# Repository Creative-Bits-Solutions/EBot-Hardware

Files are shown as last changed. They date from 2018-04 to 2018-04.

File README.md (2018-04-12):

# EBot-Hardware
EBot is a DIY ecosystem developed for students, kids, artists, and robotics enthusiasts to learn, explore and build working prototypes through experiments and games. Entire system includes an electronic development board with wide range of compactable sensors, graphical programming software based on Google Blockly, bunch of wheels, gears, motors, shafts and plastics, books and study materials that help to learn all basic concepts of mechanical designing, programing and electronic prototyping

We focus on STEM education to improve imagination, reasoning, analytical thinking and problem solving skills of kids. Let them Play, Make and Learn with EBot system.

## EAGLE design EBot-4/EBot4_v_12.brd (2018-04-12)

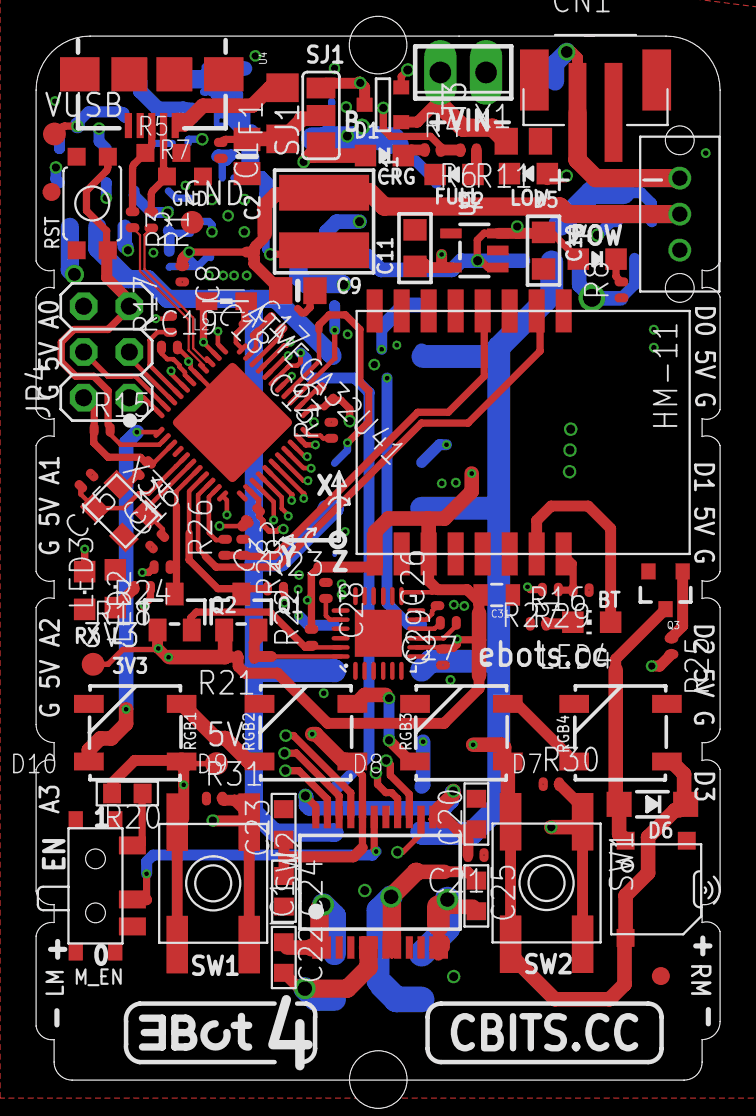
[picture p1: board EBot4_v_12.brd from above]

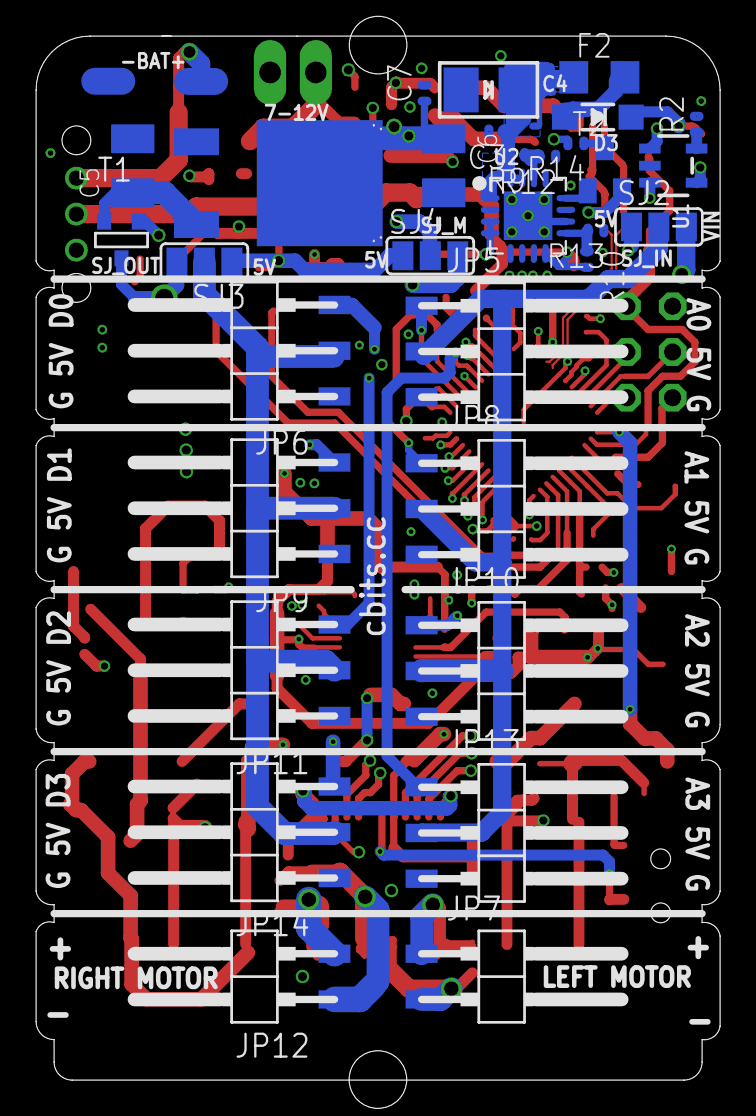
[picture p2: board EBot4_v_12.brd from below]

Board: 4 copper layers, 38.0 x 58.0 mm, 126 parts (33 on the bottom side), 84 nets.

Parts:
3V3, 5V: TPB1,27; B1,27
ATMEGA32U41: ATMEGA32U4-XUMU; QFN44ML7X7
AZ1084C1: AZ1084C
C1, C7, C12, C13, C14, C18: 100n; C0402
C2: 4.7µF; 0805-NO
C3: 2.2uF; C0402
C4: 100uF/6V; EIA3528-21/B-R
C5, C6: 22u; SMC_B
C8, C21, C26, C27: 0.1uF; C0402
C9: 10uF; 0805-NO
C10, C11: 10µF; _0805
C15, C16: 22pF; C0402
C17, C19: 1uF; C0402
C20, C23: 10uf; C0603
C22, C25: 0.1u; C0603
C24: 0.1uf; C0603
C28: 2.2nF; C0402
C29: 10nF; C0402
C31: 0.1uF; 0805
CN1: JST-PH-2-SMT
D1: YELLOW; CHIPLED_0805_NOOUTLINE
D2: GREEN; CHIPLED_0805_NOOUTLINE
D3, D6: MBR120; SOD-123
D4: red; CHIPLED_0805_NOOUTLINE
D5: RED; CHIPLED_0805_NOOUTLINE
D7, D8, D9, D10: WS2812B
EBOT_LOGO2: EBOT_NAME_6MM
F1, F2: 500mA; R1206
GND: TPB1,27; B1,27
HM-111: HM-11
IC1: TB6612FNG; SSOP24
JP2, JP3: FIDUCIAL1X2; FIDUCIAL-1X2
JP4: 3x2M; 2X03
JP5, JP6, JP8, JP9, JP10, JP11, JP13, JP14: 1X03SMD/90
JP7, JP12: 1X02SMD/90
KMR1: KMR7
L1: VLC5045-6.8uH; INDUCTOR_5X5MM_TDK_VLC5045
L2: MH2029-300Y; 0805
LED2: yellow; CHIPLED_0805
LED3: BLUE; CHIPLED_0805
LED4: CHIP-LED0805
MPU-60501: MPU-6050-1; QFN-24-4MM2
ON_OFF_SLIDE1: OS102011MA1QN1
Q1, Q2: BSS138; SOT23-WIDE@1
Q3: 2222A; SOT23-3
R1, R3: 22R; R0402
R2, R28, R29: 2K; R0402
R4: 470; R0402
R5, R7: CG0603MLC-05E; CT/CN0603
R6, R17, R18, R26, R27, R30, R31: 1K; R0402
R8, R14: 1k; R0402
R9, R10: 1.87M; R0402
R11: 10k; R0805
R12: 200K; R0402
R13: 340K; R0402
R15, R19, R21, R22, R23, R24: 10K; R0402
R16: 330; R0402
R20: 10K; R0603
R25: 270; R0402
SJ1, SJ2, SJ3, SJ4: SJ_2
SK-12C04051: SK-12C0405
SPK1: SMT-0540-S-R
SW1, SW2: SPST_TACT-EVQQ2; EVQ-Q2
T1: PMV48XP; SOT-23
T2: MMUN2133LT1G; SC59-BEC
T3: FDN340P/PMV48XP; SOT-23
U1: MCP73831T-2ACI/OT; SOT23-5
U2: TPS61030RSAR; PVQFN-16
U3: RT9193; SOT23-5@1
U4: USB-AB-MICRO-SMD
U$1, U$2: BATCON
VUSB: TPB1,27; B1,27
X1: 2POL254
X3: 16MHz KX-7; CRYSTAL-3.2-2.5

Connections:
+3V3: 3V3.TP, C11.1, C26.2, C29.2, C31.2, HM-111.RESETB, HM-111.VCC, MPU-60501.8, MPU-60501.13, Q1.1, Q2.1, R21.2, R22.2, U3.5
+5V: 5V.TP, ATMEGA32U41.2, ATMEGA32U41.14, ATMEGA32U41.24, ATMEGA32U41.34, AZ1084C1.VOUT, C6.+, C7.1, C10.1, C12.1, C13.1, C14.1, C23.1, C24.1, D4.A, D6.C, D7.1, D8.1, D9.1, D10.1, IC1.20, JP4.2, L2.1, R15.1, R20.2, R23.2, R24.2, SJ2.1, SJ3.1, SJ4.1, SPK1.-, SW1.A, SW1.A', SW2.A, SW2.A', T1.3, T3.2, U3.1, U3.3
A0: ATMEGA32U41.36, JP5.1
A1: ATMEGA32U41.37, JP8.1
A2: ATMEGA32U41.38, JP10.1
A3: ATMEGA32U41.39, JP13.1
A4: ATMEGA32U41.40, JP11.3
A5: ATMEGA32U41.41, JP14.3
AO1': C22.1, IC1.1, IC1.2, JP7.1
AO2': C22.2, IC1.5, IC1.6, JP7.2
AREF: ATMEGA32U41.42, C18.1
AVCC: ATMEGA32U41.44, C17.1, L2.2
BLE_KEY: HM-111.PIO0, R27.1, R29.2
BLE_LED: HM-111.PIO1, LED4.A
BO1': C25.2, IC1.11, IC1.12, JP12.2
BO2': C25.1, IC1.7, IC1.8, JP12.1
D0/RX: ATMEGA32U41.20, HM-111.UART_TX
D1/TX: ATMEGA32U41.21, R26.2
D4/M1: ATMEGA32U41.25, IC1.22
D5*/PWM2: ATMEGA32U41.31, IC1.15
D6*/PWM1: ATMEGA32U41.27, IC1.23
D7: ATMEGA32U41.1, JP9.3
D+: R3.1, R5.1, U4.D+
D-: R1.1, R7.1, U4.D-
GND: ATMEGA32U41.5, ATMEGA32U41.15, ATMEGA32U41.23, ATMEGA32U41.35, ATMEGA32U41.43, ATMEGA32U41.EXP, AZ1084C1.GND, C1.2, C2.2, C3.2, C4.-, C5.-, C6.-, C7.2, C8.2, C9.2, C10.2, C11.2, C12.2, C13.2, C14.2, C15.1, C16.1, C17.2, C18.2, C19.2, C20.2, C21.1, C23.2, C24.2, C26.1, C27.1, C28.1, C29.1, C31.1, CN1.2, D2.C, D5.C, D7.3, D8.3, D9.3, D10.3, GND.TP, HM-111.GND, IC1.3, IC1.4, IC1.9, IC1.10, IC1.18, JP4.6, JP5.3, JP6.1, JP8.3, JP9.1, JP10.3, JP11.1, JP13.3, JP14.1, KMR1.P$1, KMR1.P$2, LED2.C, LED3.C, MPU-60501.1, MPU-60501.9, MPU-60501.11, MPU-60501.18, Q3.2, R2.2, R5.2, R7.2, R8.1, R11.1, R12.1, R13.1, R16.1, R19.2, R28.1, R29.1, R30.1, R31.1, SK-12C04051.R, U1.2, U2.5, U2.6, U2.7, U2.10, U2.13, U2.P$18, U2.P$19, U2.P$20, U2.P$21, U2.P$22, U2.THERMAL, U3.2, U4.GND, U$2.P$1, X1.1, X3.2, X3.4
HWB: ATMEGA32U41.33, R19.1
IO8: ATMEGA32U41.28, JP6.3
IO9*/M3: ATMEGA32U41.29, IC1.17
IO10*: ATMEGA32U41.30, R25.2
IO11*/RGB: ATMEGA32U41.12, D10.4
IO12*/M4: ATMEGA32U41.26, IC1.21
IO13*: ATMEGA32U41.32, R18.1
LBI: R10.1, R13.2, U2.9
LBO: T2.B, U2.12
M2: ATMEGA32U41.22, IC1.16
MISO: ATMEGA32U41.11, JP4.1, R30.2, SW1.B, SW1.B'
MOSI: ATMEGA32U41.10, JP4.4, R31.2, SW2.B, SW2.B'
unnamed: D1.A, SJ1.1, U1.4
unnamed: LED2.A, R17.2
unnamed: C8.1, C9.1, L1.P$1, ON_OFF_SLIDE1.P$2, R10.2, U2.8
unnamed: LED3.A, R18.2
unnamed: D9.4, D10.2
unnamed: D1.C, R4.1
unnamed: D8.4, D9.2
unnamed: HM-111.UART_RX, R26.1, R28.2
unnamed: JP5.2, JP8.2, JP10.2, JP13.2, SJ2.2
unnamed: C28.2, MPU-60501.20
unnamed: C27.2, MPU-60501.10
unnamed: D7.4, D8.2
unnamed: LED4.C, R16.2
unnamed: R4.2, R6.2, U1.1
unnamed: R2.1, U1.5
unnamed: D2.A, R6.1
unnamed: L1.P$2, U2.3, U2.4
unnamed: D4.C, R8.2
unnamed: D5.A, R14.2
unnamed: R14.1, T2.C
unnamed: D3.A, F2.2
unnamed: JP6.2, JP9.2, JP11.2, JP14.2, SJ3.2
unnamed: Q3.1, R25.1
unnamed: F1.2, U4.VBUS
unnamed: C1.1, C2.1, F1.1, SJ1.2
unnamed: R9.1, R12.2, U2.14
unnamed: D6.A, Q3.3, SPK1.+
unnamed: AZ1084C1.VIN, C5.+, T1.2
unnamed: C20.1, C21.2, IC1.13, IC1.14, IC1.24, SJ4.2
unnamed: R20.1, SK-12C04051.L
RD_N: ATMEGA32U41.3, R1.2
RD_P: ATMEGA32U41.4, R3.2
RESET: ATMEGA32U41.13, JP4.5, KMR1.P$3, KMR1.P$4, R15.2
RXLED/SS: ATMEGA32U41.8, R17.1
SCK: ATMEGA32U41.9, JP4.3, R27.2
SCL_3V: MPU-60501.23, Q2.2, R22.1
SCL_5V: ATMEGA32U41.18, Q2.3, R24.1
SDA_3V: MPU-60501.24, Q1.2, R21.1
SDA_5V: ATMEGA32U41.19, Q1.3, R23.1
STBY: IC1.19, SK-12C04051.M
UCAP: ATMEGA32U41.6, C19.1
V+: CN1.1, ON_OFF_SLIDE1.P$3, U1.3, U$1.P$1
VDD: R11.2, SJ2.3, SJ3.3, SJ4.3, T1.1, T3.3, X1.2
VOUT1: C3.1, C4.+, F2.1, R9.2, U2.1, U2.15, U2.16
VUSB: ATMEGA32U41.7, D3.C, SJ1.3, T3.1, VUSB.TP
XTAL1: ATMEGA32U41.17, C16.2, X3.3
XTAL2: ATMEGA32U41.16, C15.2, X3.1

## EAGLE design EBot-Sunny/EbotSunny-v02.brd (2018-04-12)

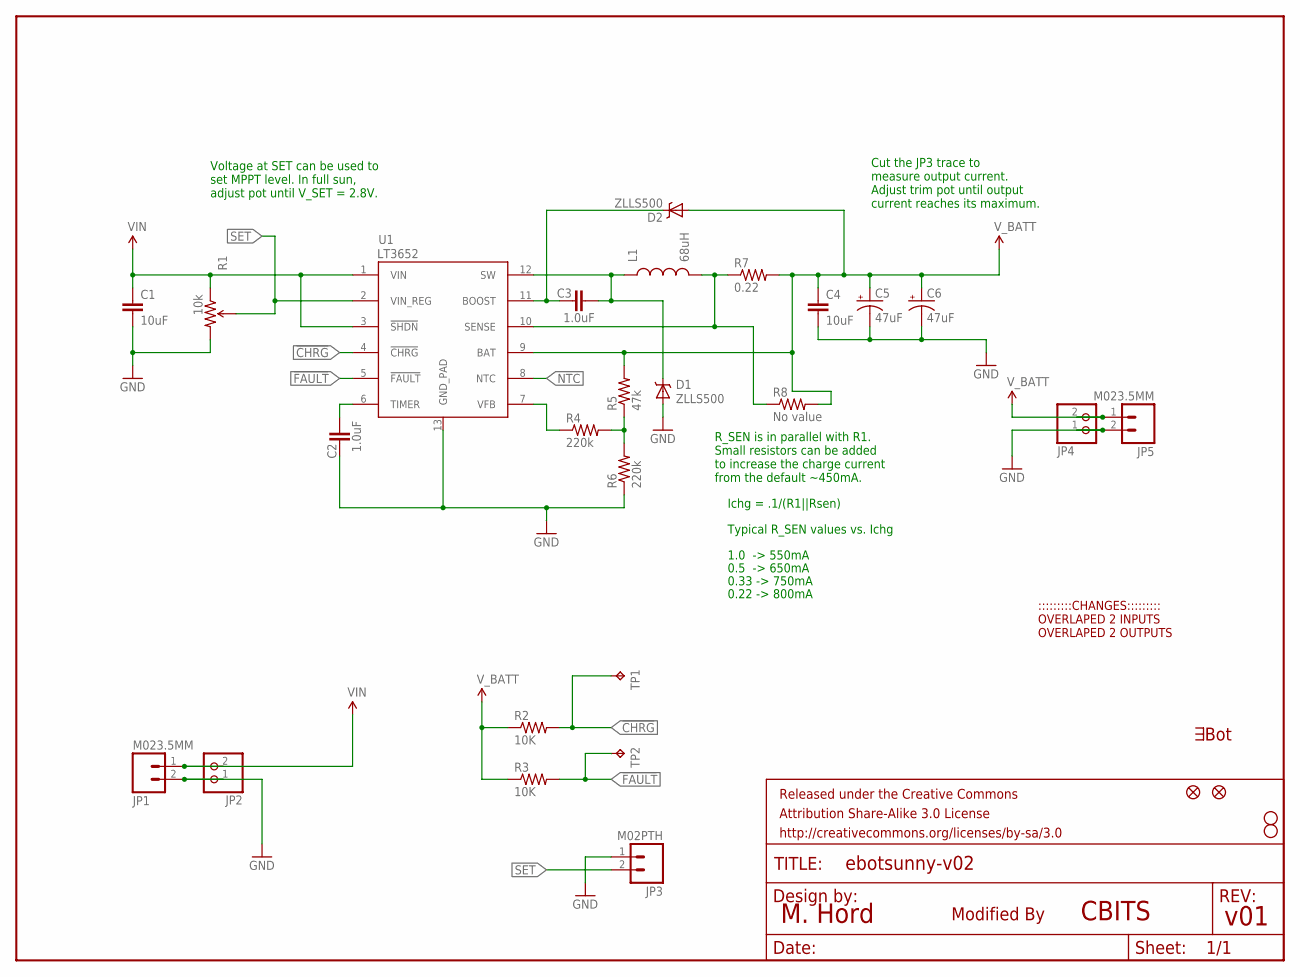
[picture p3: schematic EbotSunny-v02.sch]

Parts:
C1: 10uF; 1210
C2, C3: 1.0uF; 0603-CAP
C4: 10uF; 1206
C5, C6: 47uF; EIA3528
D1, D2: ZLLS500; SOT23
EBOT_LOGO3: EBOT_NAME_6MM
FID1, FID2: FIDUCIAL1X2; FIDUCIAL-1X2
FRAME1: FRAME-LETTER; CREATIVE_COMMONS
JP1, JP5: M023.5MM; SCREWTERMINAL-3.5MM-2
JP2, JP4: PINHD-1X2; 1X02
JP3: M02PTH; 1X02
L1: 68uH; CR75
R1: 10k; TRIMPOT-3MM
R2, R3: 10K; 0603-RES
R4, R6: 220k; 0603-RES
R5: 47k; 0603-RES
R7: 0.22; 0805
R8: No value; 0805
STANDOFF1, STANDOFF2: STAND-OFF
TP1, TP2: TPB1,27; B1,27
U1: LT3652; MSOP-12_GND

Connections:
!CHRG: R2.2, TP1.TP, U1.4 (!CHRG)
!FAULT: R3.2, TP2.TP, U1.5 (!FAULT)
BOOST: C3.1, D2.3 (C), U1.11 (BOOST)
FB: R4.2, R5.1, R6.2
GND: C1.2, C2.1, C4.2, C5.C (-), C6.C (-), D1.1 (A), JP1.2, JP2.1, JP3.1, JP4.1, JP5.2, R1.3 (CW), R6.1, U1.13 (GND_PAD)
unnamed: R4.1, U1.7 (VFB)
NTC: U1.8 (NTC)
SENSE: L1.P$2 (2), R7.1, R8.1, U1.10 (SENSE)
SET: JP3.2, R1.2 (WIPER), U1.2 (VIN_REG)
SW: C3.2, D1.3 (C), L1.P$1 (1), U1.12 (SW)
TIMER: C2.2, U1.6 (TIMER)
VIN: C1.1, JP1.1, JP2.2, R1.1 (CCW), U1.1 (VIN), U1.3 (!SHDN)
V_BATT: C4.1, C5.A (+), C6.A (+), D2.1 (A), JP4.2, JP5.1, R2.1, R3.1, R5.2, R7.2, R8.2, U1.9 (BAT)

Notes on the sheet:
Cut the JP3 trace to measure output current. Adjust trim pot until output current reaches its maximum.
R_SEN is in parallel with R1. Small resistors can be added to increase the charge current from the default ~450mA.
0.22 -> 800mA
Ichg = .1/(R1||Rsen)
Typical R_SEN values vs. Ichg
1.0 -> 550mA
0.33 -> 750mA
0.5 -> 650mA
Voltage at SET can be used to set MPPT level. In full sun, adjust pot until V_SET = 2.8V.
v01
M. Hord
CBITS
Modified By
:::::::::CHANGES::::::::: OVERLAPED 2 INPUTS OVERLAPED 2 OUTPUTS

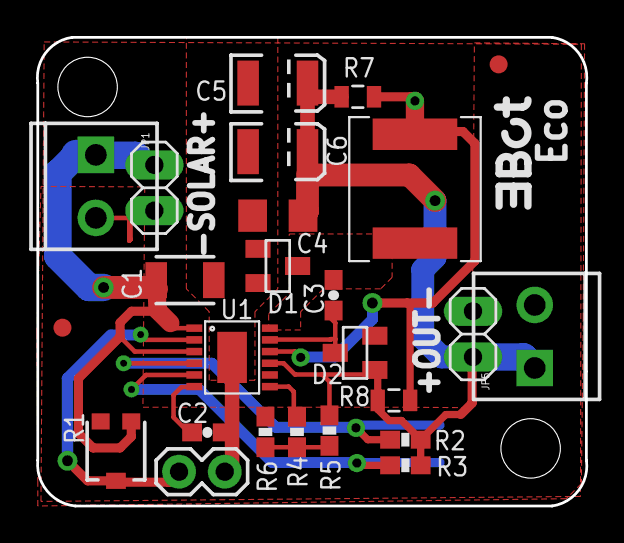
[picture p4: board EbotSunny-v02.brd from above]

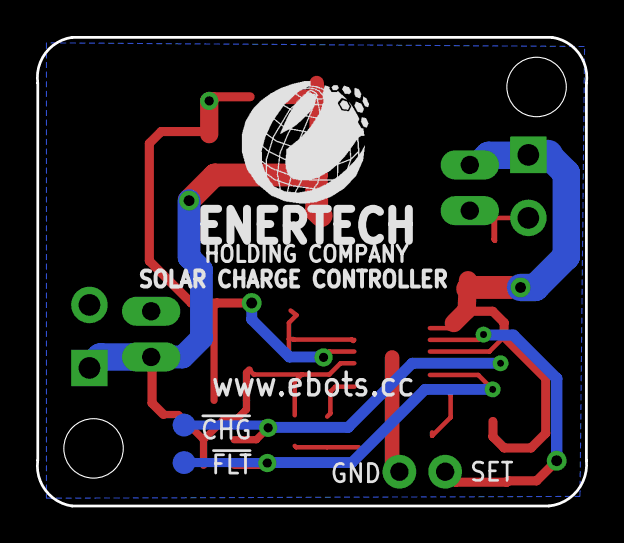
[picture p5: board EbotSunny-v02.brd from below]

Board: 2 copper layers, 30.5 x 26.0 mm, 31 parts (2 on the bottom side), 12 nets.

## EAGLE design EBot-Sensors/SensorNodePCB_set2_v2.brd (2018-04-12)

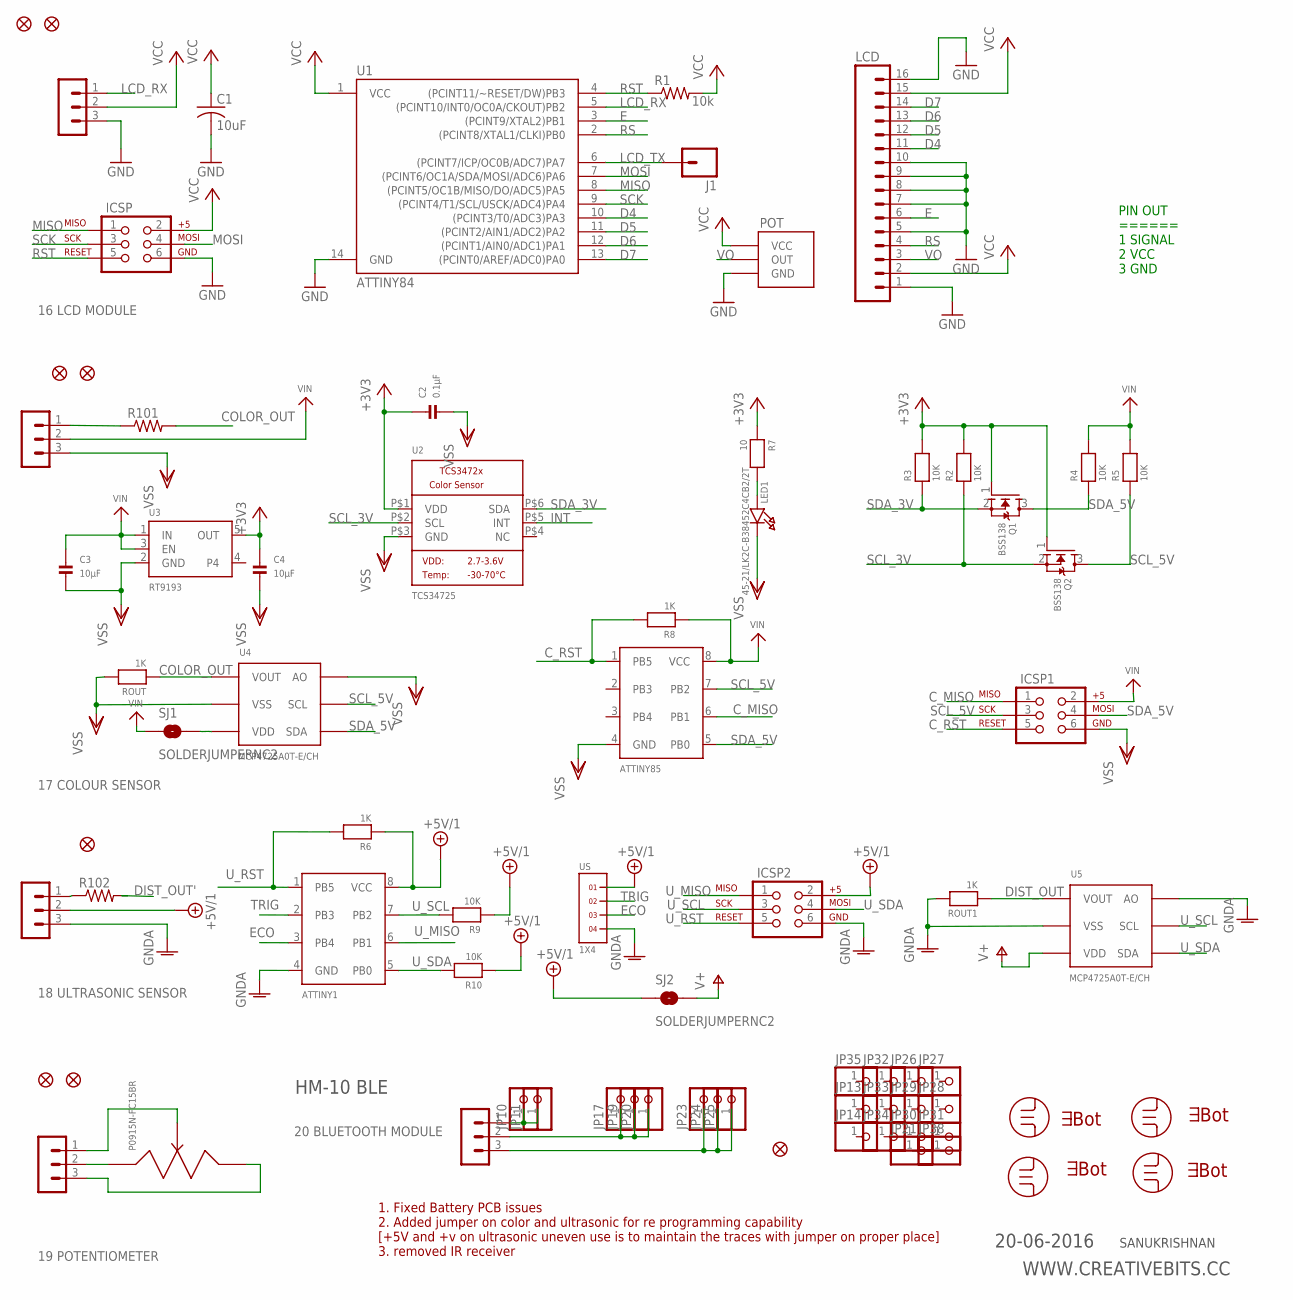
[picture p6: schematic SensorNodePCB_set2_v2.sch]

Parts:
ATTINY1, ATTINY85: ATTINY45; SOIC8
C1: 10uF; C1206
C2: 0.1µF; _0805
C3, C4: 10µF; _0805
COLORSENSOR: MA03-1
ICSP, ICSP1, ICSP2: AVR_SPI_PRG_6NS; 2X3-NS
J1: M01NOSILK-KIT; 1X01NS-KIT
JP1, JP2, JP4, JP6, JP9, JP12, JP15, JP18: FIDUCIAL1X2; FIDUCIAL-1X2
JP10, JP11, JP13, JP14, JP17, JP19, JP20, JP21, JP23, JP24, JP25, JP26, JP27, JP28, JP29, JP30, JP31, JP32, JP33, JP34, JP35, JP38: PINHD-1X1CB; 1X01-CLEANBIG
LCD: M16LONGPADS; 1X16_LONGPADS
LCD_NODE: MA03-1
LED1: 45-21/LK2C-B38452C4CB2/2T; EVERLIGHT_45-21
POT: TRIMMER_EVN
POT1: P0915N-FC15BR
POTENTIOMETER: MA03-1
Q1, Q2: BSS138; SOT23-WIDE
R1: 10k; M0805
R2, R3, R4, R5, R9, R10: 10K; _0805
R6, R8: 1K; _0805
R7: 10; _0805
R101, R102: R-US_M0805; M0805
ROUT, ROUT1: 1K; _0805
SJ1, SJ2: SOLDERJUMPERNC2; SJ_2S-NOTRACE
U1: ATTINY84; SO14
U2: TCS34725; TCS3472_FN6
U3: RT9193; SOT23-5
U4, U5: MCP4725
U$30, U$32, U$33, U$34: EBOT_LOGO_6MMX6MM; EBOT_6MMX6MM
U$35, U$37, U$38, U$39: EBOT_NAME_6MM
ULTRASONICSENSOR, ULTRASONICSENSOR1: MA03-1
US: 1X4

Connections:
+3V3: C2.1, C4.1, Q1.1 (G), Q2.1 (G), R2.2, R3.2, R7.1, U2.P$1 (VDD), U3.5 (OUT)
+5V/1: ATTINY1.8 (VCC), ICSP2.2, R6.1, R9.1, R10.1, SJ2.1, ULTRASONICSENSOR.2, US.1
COLOR_OUT: R101.2, ROUT.1, U4.P$1 (VOUT)
C_MISO: ATTINY85.6 (PB1), ICSP1.1
C_RST: ATTINY85.1 (PB5), ICSP1.5, R8.2
D4: LCD.11, U1.10 ((PCINT3/T0/ADC3)PA3)
D5: LCD.12, U1.11 ((PCINT2/AIN1/ADC2)PA2)
D6: LCD.13, U1.12 ((PCINT1/AIN0/ADC1)PA1)
D7: LCD.14, U1.13 ((PCINT0/AREF/ADC0)PA0)
DIST_OUT: R102.2, ROUT1.1, U5.P$1 (VOUT)
DIST_OUT': R102.1, ULTRASONICSENSOR.1
E: LCD.6, U1.3 ((PCINT9/XTAL2)PB1)
ECO: ATTINY1.3 (PB4), US.3
GND: C1.2, ICSP.6, LCD.1, LCD.5, LCD.7, LCD.8, LCD.9, LCD.10, LCD.16, LCD_NODE.3, POT.P$2 (GND), U1.14 (GND)
GNDA: ATTINY1.4 (GND), ICSP2.6, ROUT1.2, U5.P$2 (VSS), U5.P$6 (AO), ULTRASONICSENSOR.3, US.4
INT: U2.P$5 (INT)
LCD_RX: LCD_NODE.1, U1.5 ((PCINT10/INT0/OC0A/CKOUT)PB2)
LCD_TX: J1.1, U1.6 ((PCINT7/ICP/OC0B/ADC7)PA7)
MISO: ICSP.1, U1.8 ((PCINT5/OC1B/MISO/DO/ADC5)PA5)
MOSI: ICSP.4, U1.7 ((PCINT6/OC1A/SDA/MOSI/ADC6)PA6)
unnamed: LED1.A, R7.2
unnamed: POT1.VCC, POTENTIOMETER.2
unnamed: SJ1.2, U4.P$3 (VDD)
unnamed: COLORSENSOR.1, R101.1
unnamed: POT1.GND, POTENTIOMETER.3
unnamed: JP10.1, JP11.1, ULTRASONICSENSOR1.1
unnamed: JP17.1, JP19.1, JP20.1, ULTRASONICSENSOR1.2
unnamed: JP23.1, JP24.1, JP25.1, ULTRASONICSENSOR1.3
POT_OUT: POT1.OUT, POTENTIOMETER.1
RS: LCD.4, U1.2 ((PCINT8/XTAL1/CLKI)PB0)
RST: ICSP.5, R1.1, U1.4 ((PCINT11/~RESET/DW)PB3)
SCK: ICSP.3, U1.9 ((PCINT4/T1/SCL/USCK/ADC4)PA4)
SCL_3V: Q2.2 (S), R2.1, U2.P$2 (SCL)
SCL_5V: ATTINY85.7 (PB2), ICSP1.3, Q2.3 (D), R5.1, U4.P$5 (SCL)
SDA_3V: Q1.2 (S), R3.1, U2.P$6 (SDA)
SDA_5V: ATTINY85.5 (PB0), ICSP1.4, Q1.3 (D), R4.1, U4.P$4 (SDA)
TRIG: ATTINY1.2 (PB3), US.2
U_MISO: ATTINY1.6 (PB1), ICSP2.1
U_RST: ATTINY1.1 (PB5), ICSP2.5, R6.2
U_SCL: ATTINY1.7 (PB2), ICSP2.3, R9.2, U5.P$5 (SCL)
U_SDA: ATTINY1.5 (PB0), ICSP2.4, R10.2, U5.P$4 (SDA)
V+: SJ2.2, U5.P$3 (VDD)
VCC: C1.1, ICSP.2, LCD.2, LCD.15, LCD_NODE.2, POT.P$1 (VCC), R1.2, U1.1 (VCC)
VIN: ATTINY85.8 (VCC), C3.1, COLORSENSOR.2, ICSP1.2, R4.2, R5.2, R8.1, SJ1.1, U3.1 (IN), U3.3 (EN)
VO: LCD.3, POT.P$3 (OUT)
VSS: ATTINY85.4 (GND), C2.2, C3.2, C4.2, COLORSENSOR.3, ICSP1.6, LED1.K (C), ROUT.2, U2.P$3 (GND), U3.2 (GND), U4.P$2 (VSS), U4.P$6 (AO)

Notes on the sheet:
16 LCD MODULE
PIN OUT ====== 1 SIGNAL 2 VCC 3 GND
17 COLOUR SENSOR
18 ULTRASONIC SENSOR
19 POTENTIOMETER
20 BLUETOOTH MODULE
HM-10 BLE
20-06-2016
WWW.CREATIVEBITS.CC
SANUKRISHNAN
1. Fixed Battery PCB issues 2. Added jumper on color and ultrasonic for re programming capability [+5V and +v on ultrasonic uneven use is to maintain the traces with jumper on proper place] 3. removed IR receiver

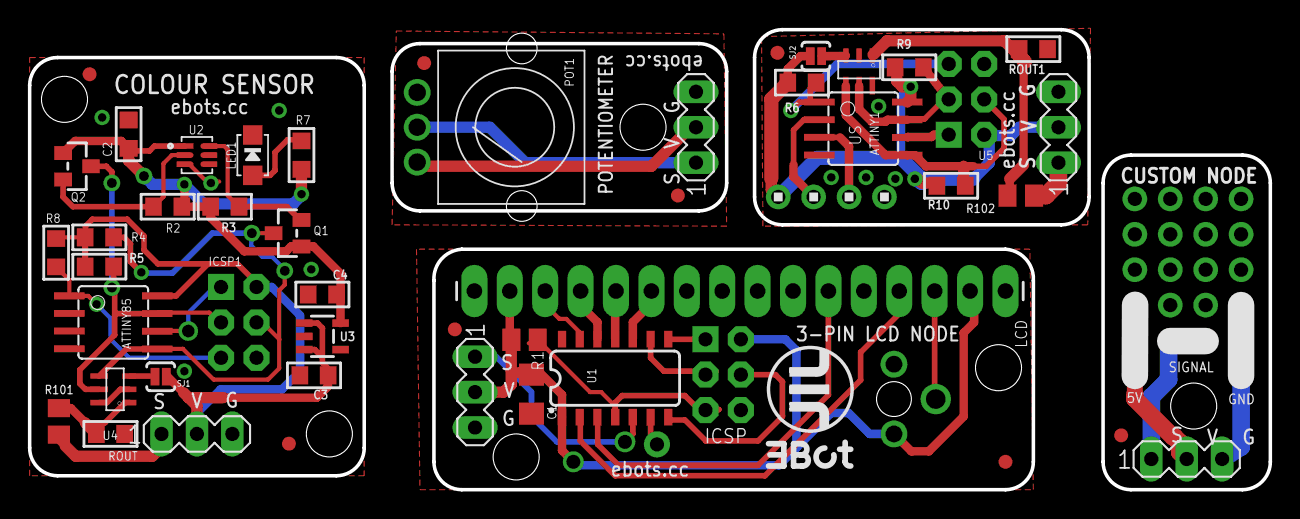
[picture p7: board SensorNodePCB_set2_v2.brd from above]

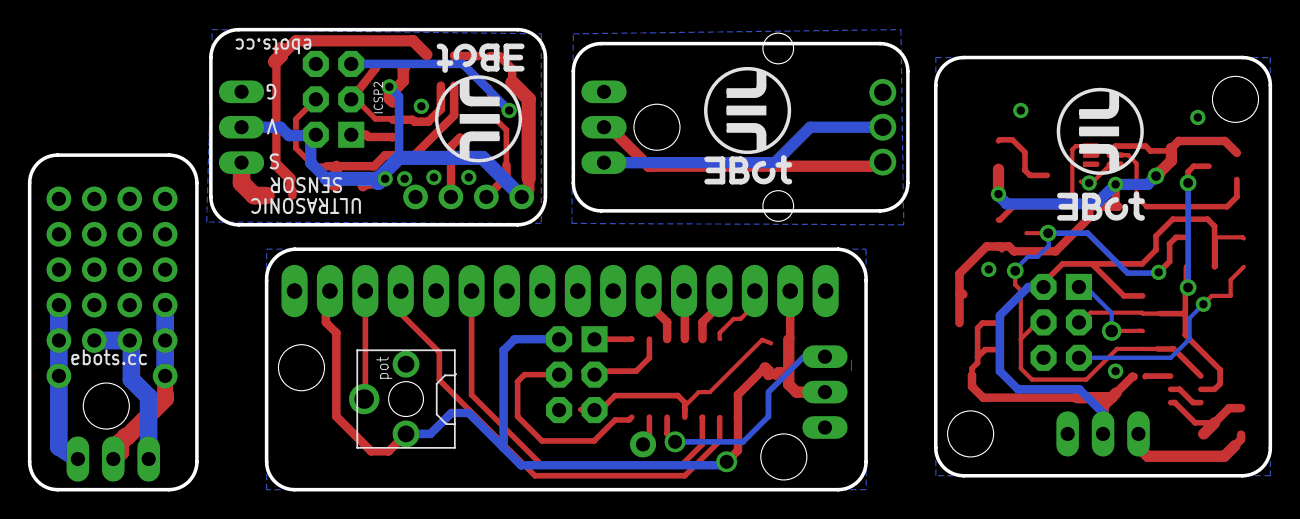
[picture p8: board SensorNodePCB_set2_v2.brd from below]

Board: 2 copper layers, 89.0 x 33.0 mm, 87 parts (8 on the bottom side), 45 nets.

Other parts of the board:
JP3, JP5, JP7, JP8, JP16, JP22: STAND-OFF

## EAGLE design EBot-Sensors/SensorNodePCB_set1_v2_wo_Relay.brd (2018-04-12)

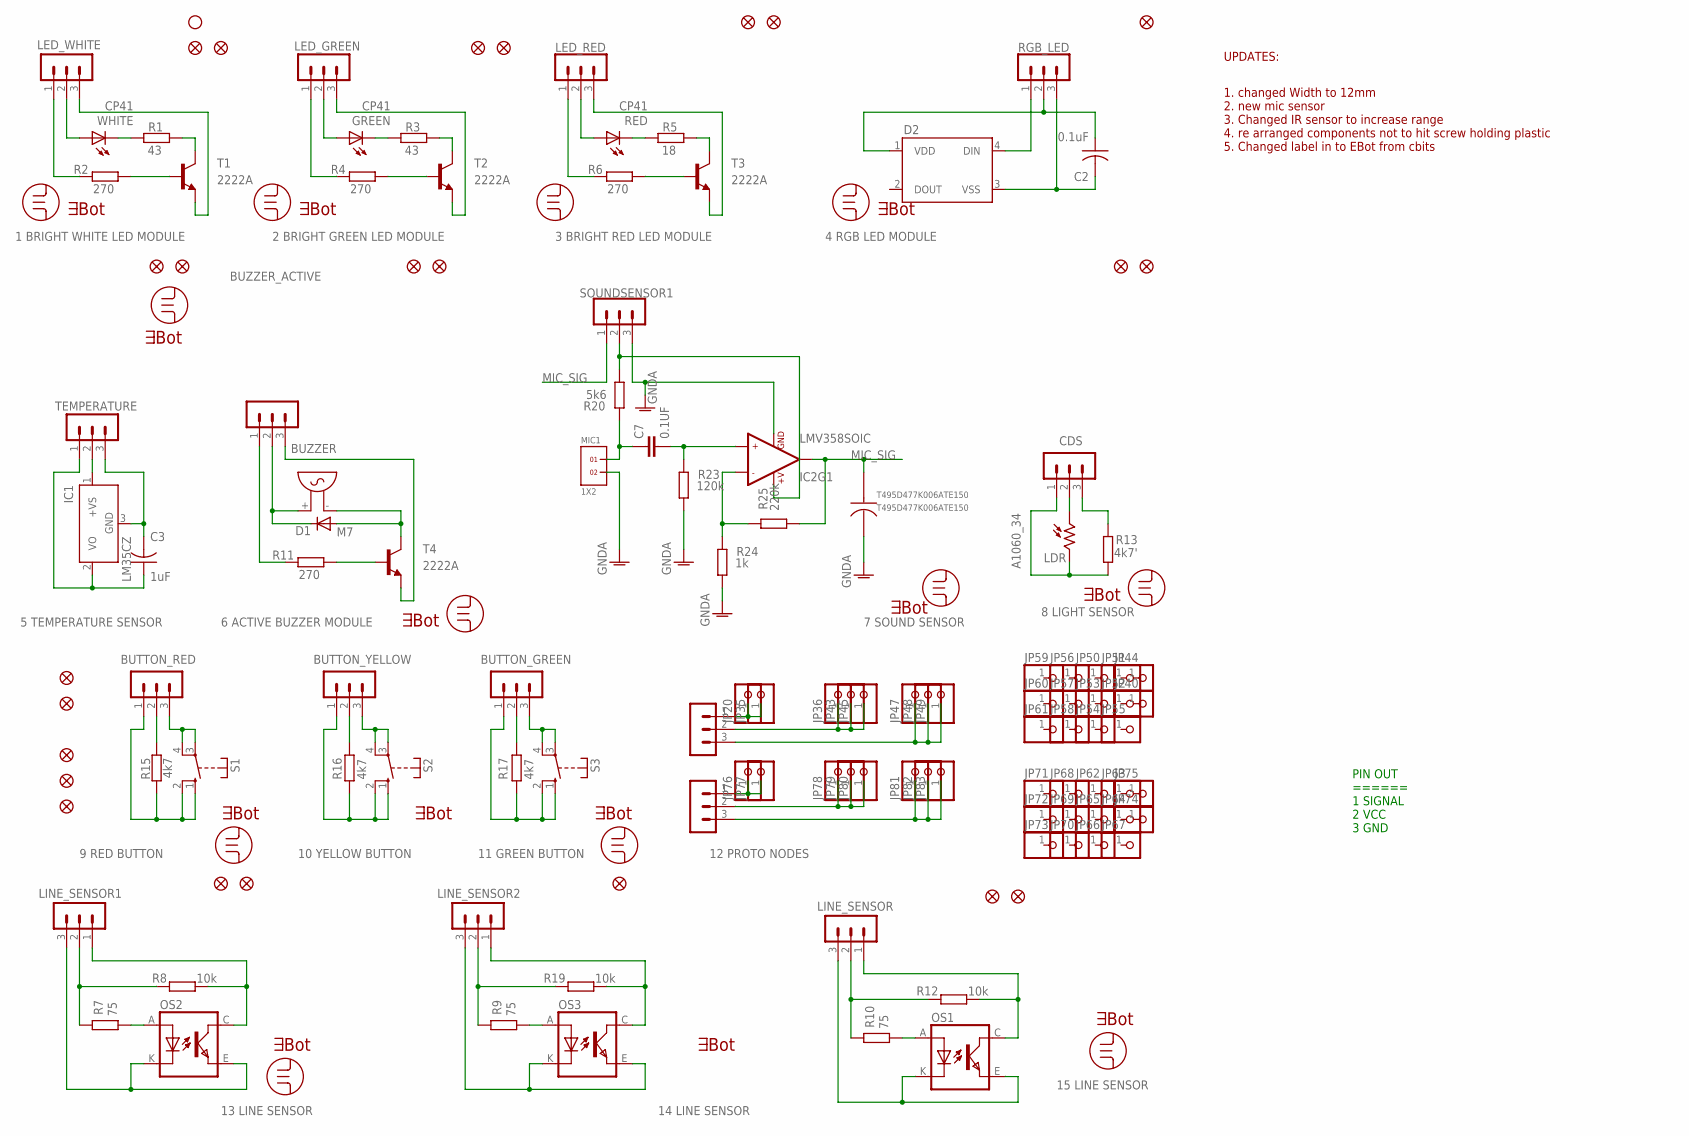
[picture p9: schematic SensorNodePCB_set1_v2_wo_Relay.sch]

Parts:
BUTTON_GREEN: MA03-1
BUTTON_RED: MA03-1
BUTTON_YELLOW: MA03-1
BUZZER: F/QMX
BUZZER_ACTIVE: MA03-1
C2: 0.1uF; C0805
C3: 1uF; C0805
C7: 0.1UF; 0805
CDS: MA03-1
D1: M7; DO214AC
D2: WS2812B
GREEN: CP41; CP41B
IC1: LM35CZ; TO92
IC2: LMV358SOIC; SO08
JP1: STAND-OFF
JP2, JP4, JP6, JP7, JP12, JP18, JP19, JP23, JP24, JP25, JP26, JP28, JP29, JP31, JP32, JP33, JP34, JP37, JP38, JP39, JP41, JP42, JP46: FIDUCIAL1X2; FIDUCIAL-1X2
JP20, JP35, JP36, JP40, JP43, JP44, JP45, JP47, JP48, JP49, JP50, JP51, JP52, JP53, JP54, JP55, JP56, JP57, JP58, JP59, JP60, JP61, JP62, JP63, JP64, JP65, JP66, JP67, JP68, JP69, JP70, JP71, JP72, JP73, JP74, JP75, JP76, JP77, JP78, JP79, JP80, JP81, JP82, JP83: PINHD-1X1CB; 1X01-CLEANBIG
LDR: A1060_34; T0-46-A10XX
LED_GREEN: MA03-1
LED_RED: MA03-1
LED_WHITE: MA03-1
LINE_SENSOR, LINE_SENSOR1, LINE_SENSOR2: MA03-1
MIC1: 1X2
OS1, OS2, OS3: TCRT5000
R1, R3: 43; R0805
R2, R4, R6, R11: 270; R0805
R5: 18; R0805
R7, R9, R10: 75; R0805
R8, R12, R19: 10k; R0805
R13: 4k7'; R0805
R15, R16, R17: 4k7; R0805
R20: 5k6; R0805
R23: 120k; R0805
R24: 1k; R0805
R25: 220k; R0805
RED: CP41; CP41B
RGB_LED: MA03-1
S1, S2, S3: RACON12
SOUNDSENSOR1: MA03-1
T1, T2, T3, T4: 2222A; SOT23-3
TEMPERATURE: MA03-1
U$1, U$3, U$4, U$6, U$8, U$9, U$10, U$12, U$13, U$14, U$15, U$16: EBOT_LOGO_6MMX6MM; EBOT_6MMX6MM
U$11: T495D477K006ATE150
U$17, U$18, U$20, U$21, U$22, U$23, U$24, U$25, U$26, U$27, U$29, U$30, U$31: EBOT_NAME_6MM
ULTRASONICSENSOR1, ULTRASONICSENSOR2: MA03-1
WHITE: CP41; CP41B

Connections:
GNDA: IC2.4 (GND), MIC1.2, R23.1, R24.1, SOUNDSENSOR1.3, U$11.-
MIC_SIG: IC2.1 (OUT1), R25.1, SOUNDSENSOR1.1, U$11.+
unnamed: LED_WHITE.1, R2.2
unnamed: R2.1, T1.1 (B)
unnamed: R1.2, WHITE.1 (C), WHITE.4 (C)
unnamed: R1.1, T1.3 (C)
unnamed: R4.1, T2.1 (B)
unnamed: LED_WHITE.2, WHITE.2 (A), WHITE.3 (A)
unnamed: GREEN.1 (C), GREEN.4 (C), R3.2
unnamed: LED_GREEN.1, R4.2
unnamed: R3.1, T2.3 (C)
unnamed: GREEN.2 (A), GREEN.3 (A), LED_GREEN.2
unnamed: R6.1, T3.1 (B)
unnamed: R5.2, RED.1 (C), RED.4 (C)
unnamed: LED_RED.1, R6.2
unnamed: R5.1, T3.3 (C)
unnamed: LED_RED.2, RED.2 (A), RED.3 (A)
unnamed: D2.4 (DIN), RGB_LED.1
unnamed: C2.1, D2.1 (VDD), RGB_LED.2
unnamed: C2.2, D2.3 (VSS), RGB_LED.3
unnamed: BUTTON_RED.1, R15.2, S1.1 (S), S1.2 (S)
unnamed: BUTTON_RED.2, R15.1
unnamed: BUTTON_YELLOW.1, R16.2, S2.1 (S), S2.2 (S)
unnamed: LED_WHITE.3, T1.2 (E)
unnamed: JP20.1, JP35.1, ULTRASONICSENSOR1.1
unnamed: R11.1, T4.1 (B)
unnamed: LED_GREEN.3, T2.2 (E)
unnamed: LED_RED.3, T3.2 (E)
unnamed: IC1.1 (+VS), TEMPERATURE.2
unnamed: BUZZER_ACTIVE.1, R11.2
unnamed: BUZZER.- (1), D1.A, T4.3 (C)
unnamed: BUZZER.+ (2), BUZZER_ACTIVE.2, D1.C
unnamed: BUZZER_ACTIVE.3, T4.2 (E)
unnamed: C3.2, IC1.3 (GND), TEMPERATURE.3
unnamed: C3.1, IC1.2 (VO), TEMPERATURE.1
unnamed: LINE_SENSOR.3, OS1.E (EMITTER), OS1.K (CATHODE)
unnamed: LINE_SENSOR.2, R10.1, R12.1
unnamed: OS1.A (ANODE), R10.2
unnamed: CDS.1, LDR.2, R13.2
unnamed: CDS.2, LDR.1
unnamed: CDS.3, R13.1
unnamed: LINE_SENSOR.1, OS1.C (COLLECTOR), R12.2
unnamed: JP36.1, JP43.1, JP45.1, ULTRASONICSENSOR1.2
unnamed: JP47.1, JP48.1, JP49.1, ULTRASONICSENSOR1.3
unnamed: JP76.1, JP77.1, ULTRASONICSENSOR2.1
unnamed: BUTTON_GREEN.1, R17.2, S3.1 (S), S3.2 (S)
unnamed: BUTTON_GREEN.3, S3.3, S3.4
unnamed: JP78.1, JP79.1, JP80.1, ULTRASONICSENSOR2.2
unnamed: BUTTON_YELLOW.2, R16.1
unnamed: JP81.1, JP82.1, JP83.1, ULTRASONICSENSOR2.3
unnamed: BUTTON_GREEN.2, R17.1
unnamed: LINE_SENSOR1.3, OS2.E (EMITTER), OS2.K (CATHODE)
unnamed: LINE_SENSOR1.2, R7.1, R8.1
unnamed: LINE_SENSOR1.1, OS2.C (COLLECTOR), R8.2
unnamed: OS2.A (ANODE), R7.2
unnamed: LINE_SENSOR2.3, OS3.E (EMITTER), OS3.K (CATHODE)
unnamed: LINE_SENSOR2.2, R9.1, R19.1
unnamed: LINE_SENSOR2.1, OS3.C (COLLECTOR), R19.2
unnamed: OS3.A (ANODE), R9.2
unnamed: BUTTON_YELLOW.3, S2.3, S2.4
unnamed: IC2.8 (+V), R20.1, SOUNDSENSOR1.2
unnamed: C7.1, MIC1.1, R20.2
unnamed: BUTTON_RED.3, S1.3, S1.4
unnamed: C7.2, IC2.3 (+IN1), R23.2
unnamed: IC2.2 (-IN1), R24.2, R25.2

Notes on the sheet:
1 BRIGHT WHITE LED MODULE
2 BRIGHT GREEN LED MODULE
3 BRIGHT RED LED MODULE
4 RGB LED MODULE
6 ACTIVE BUZZER MODULE
5 TEMPERATURE SENSOR
8 LIGHT SENSOR
7 SOUND SENSOR
PIN OUT ====== 1 SIGNAL 2 VCC 3 GND
9 RED BUTTON
10 YELLOW BUTTON
11 GREEN BUTTON
12 PROTO NODES
13 LINE SENSOR
14 LINE SENSOR
15 LINE SENSOR
UPDATES:
1. changed Width to 12mm 2. new mic sensor 3. Changed IR sensor to increase range 4. re arranged components not to hit screw holding plastic 5. Changed label in to EBot from cbits

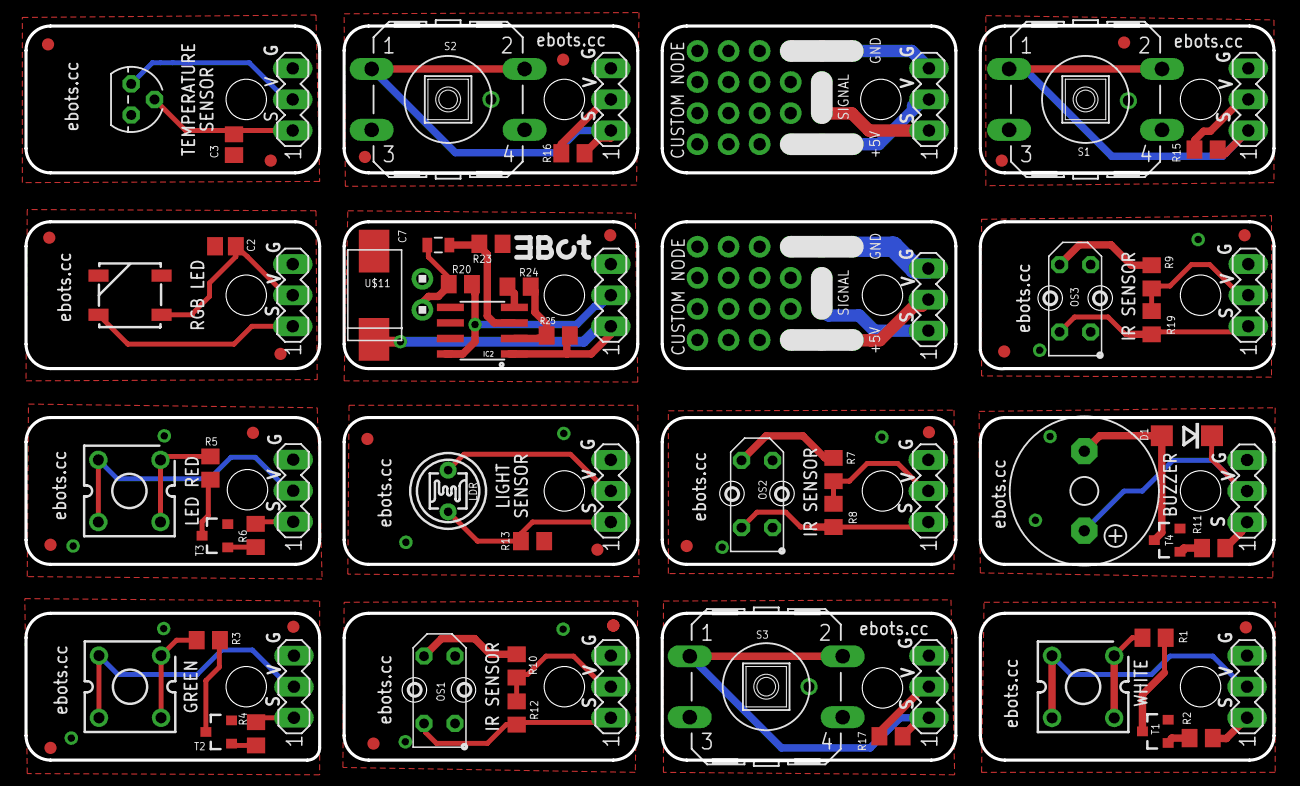
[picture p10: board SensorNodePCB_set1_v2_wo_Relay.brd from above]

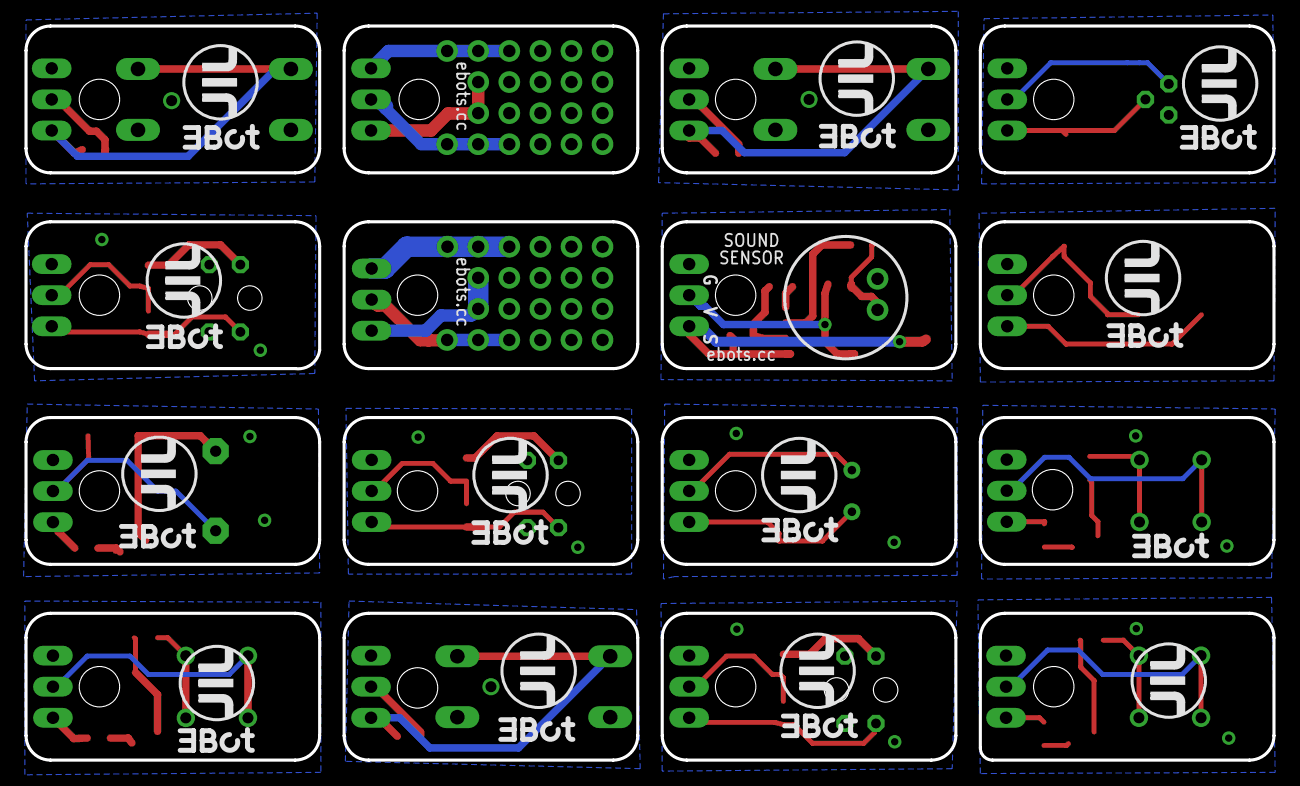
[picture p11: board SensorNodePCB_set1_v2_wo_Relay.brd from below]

Board: 2 copper layers, 102.0 x 60.0 mm, 169 parts (24 on the bottom side), 65 nets.

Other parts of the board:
JP3, JP5, JP8, JP9, JP10, JP11, JP13, JP14, JP15, JP16, JP17, JP21, JP22, JP27, JP30: STAND-OFF

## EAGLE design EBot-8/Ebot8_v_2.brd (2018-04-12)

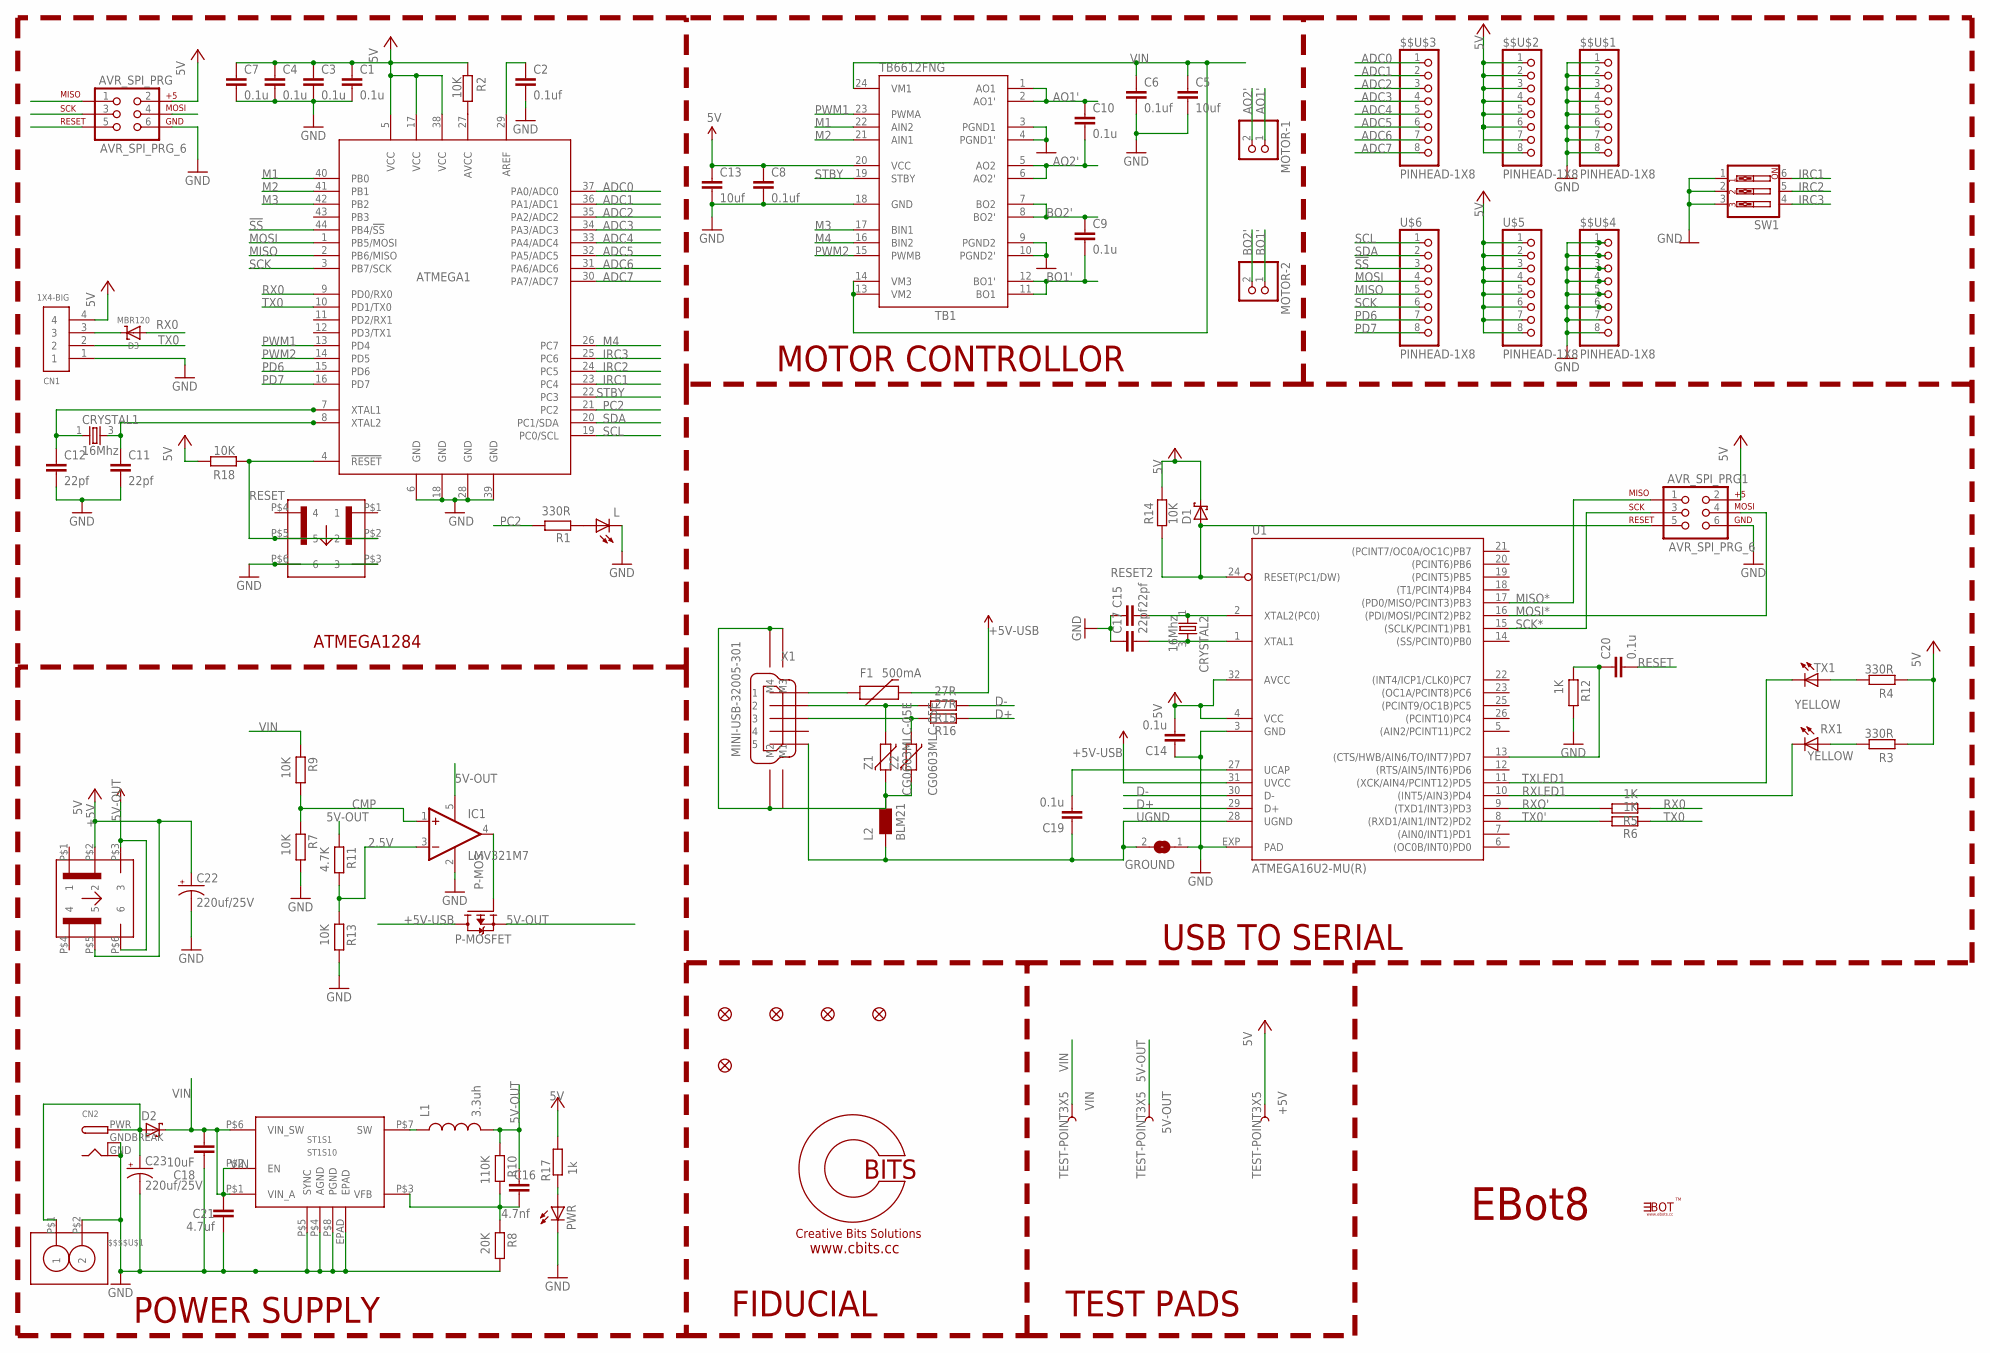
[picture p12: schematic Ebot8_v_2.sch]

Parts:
5V-OUT: TEST-POINT3X5; PAD.03X.05
$$$$U$1: SCREW_CONNECTOR-2PIN-; SCREW_CONNECTOR-2PIN-5.08MM
$$U$1, $$U$2, $$U$3, $$U$4: PINHEAD-1X8
+5V: TEST-POINT3X5; PAD.03X.05
ATMEGA1: ATMEGA164A/PA/324A/PA/644A/PA/1284/P; 44TQFP
AVR_SPI_PRG, AVR_SPI_PRG1: AVR_SPI_PRG_6; 2X3
C1, C3, C4, C7, C9, C10, C14, C19, C20: 0.1u; C0603
C2, C6, C8: 0.1uf; C0603
C5, C13: 10uf; C0603
C11, C12, C15, C17: 22pf; C0603
C16: 4.7nf; C0603
C18: 10uF; C0603
C21: 4.7uf; C0603
C22, C23: 220uf/25V; E2,5-6
CN1: 1X4-BIG; 1X04-BIG
CN2: DCBARRELPTH; DCJACK_2MM_PTH
CRYSTAL1, CRYSTAL2: 16Mhz; CRYSTAL-4PIN
D1, D2: SCHOTTKY-DIODESMA2; SCHOTTKY_SMA
D3: MBR120; SOD-123
F1: 500mA; PTC-1206
FID1, FID2, FID3, FID4, FID100: FIDUCIAL1.5X3; FIDUCIAL-1.5X3
GROUND: SJ
IC1: LMV321M7; SC70-5L
L: LEDCHIP-LED0603; CHIP-LED0603
L1: 3.3uh; CR54
L2: BLM21; 0805
LOGO1: CBITS_LOGO
MOTOR-1, MOTOR-2: PINHD-1X2; 1X02
P-MOS: P-MOSFET; SOT23-R
POWER: PUSHBUTTON_SWITCH-CW179-ND; PUSHBUTTON_SWITCH
PWR: LEDCHIP-LED0603; CHIP-LED0603
R1, R3, R4: 330R; R0603
R2, R7, R9, R13, R14, R18: 10K; R0603
R5, R6, R12: 1K; R0603
R8: 20K; R0603
R10: 110K; R0603
R11: 4.7K; R0603
R15, R16: 27R; R0603
R17: 1k; R0603
RESET: PUSHBUTTON_SWITCH-ON-MOM; PUSHBUTTON_SWITCH
RX1: YELLOW; CHIP-LED0603
ST1S1: ST1S10
SW1: SW_DIP-3; EDG-03
TB1: TB6612FNG; SSOP24
TX1: YELLOW; CHIP-LED0603
U1: ATMEGA16U2-MU(R); SMARTPRJ_ATMEL_QFN32
U$5, U$6: PINHEAD-1X8
U$14: EBOT_LOGO
VIN: TEST-POINT3X5; PAD.03X.05
X1: MINI-USB-32005-301; 32005-301
Z1, Z2: CG0603MLC-05E; CT/CN0603

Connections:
2.5V: IC1.3 (-IN), R11.2, R13.1
5V-OUT: 5V-OUT.P$1, C16.1, IC1.5 (V+), L1.P$2 (2), P-MOS.2 (S), POWER.P$3 (3), POWER.P$6 (6), R10.1, R11.1
!SS: ATMEGA1.44 (PB4/!SS), U$6.3
+5V: $$U$2.1, $$U$2.2, $$U$2.3, $$U$2.4, $$U$2.5, $$U$2.6, $$U$2.7, $$U$2.8, +5V.P$1, ATMEGA1.5 (VCC), ATMEGA1.17 (VCC), ATMEGA1.38 (VCC), AVR_SPI_PRG.2, AVR_SPI_PRG1.2, C1.1, C3.1, C4.1, C7.1, C8.1, C13.1, C14.2, C22.+, CN1.4, D1.C, POWER.P$2 (2), POWER.P$5 (5), R2.1, R3.1, R4.1, R14.2, R17.2, R18.2, TB1.20 (VCC), U1.4 (VCC), U1.32 (AVCC), U$5.1, U$5.2, U$5.3, U$5.4, U$5.5, U$5.6, U$5.7, U$5.8
+5V-USB: F1.2, P-MOS.3 (D), U1.31 (UVCC)
ADC0: $$U$3.1, ATMEGA1.37 (PA0/ADC0)
ADC1: $$U$3.2, ATMEGA1.36 (PA1/ADC1)
ADC2: $$U$3.3, ATMEGA1.35 (PA2/ADC2)
ADC3: $$U$3.4, ATMEGA1.34 (PA3/ADC3)
ADC4: $$U$3.5, ATMEGA1.33 (PA4/ADC4)
ADC5: $$U$3.6, ATMEGA1.32 (PA5/ADC5)
ADC6: $$U$3.7, ATMEGA1.31 (PA6/ADC6)
ADC7: $$U$3.8, ATMEGA1.30 (PA7/ADC7)
AO1': C10.1, MOTOR-1.1, TB1.1 (AO1), TB1.2 (AO1')
AO2': C10.2, MOTOR-1.2, TB1.5 (AO2), TB1.6 (AO2')
AREF: ATMEGA1.29 (AREF), C2.1
BO1': C9.2, MOTOR-2.1, TB1.11 (BO1), TB1.12 (BO1')
BO2': C9.1, MOTOR-2.2, TB1.7 (BO2), TB1.8 (BO2')
CMP: IC1.1 (+IN), R7.1, R9.2
D+: R16.1, U1.29 (D+)
D-: R15.1, U1.30 (D-)
GATE_CMD: IC1.4 (OUT), P-MOS.1 (G)
GND: $$$$U$1.P$2 (2), $$U$1.1, $$U$1.2, $$U$1.3, $$U$1.4, $$U$1.5, $$U$1.6, $$U$1.7, $$U$1.8, $$U$4.1, $$U$4.2, $$U$4.3, $$U$4.4, $$U$4.5, $$U$4.6, $$U$4.7, $$U$4.8, ATMEGA1.6 (GND), ATMEGA1.18 (GND), ATMEGA1.28 (GND), ATMEGA1.39 (GND), AVR_SPI_PRG.6, AVR_SPI_PRG1.6, C1.2, C2.2, C3.2, C4.2, C5.2, C6.2, C7.2, C8.2, C11.2, C12.2, C13.2, C14.1, C15.1, C17.1, C18.2, C21.2, C22.-, C23.-, CN1.1, CN2.GND, CN2.GNDBREAK, GROUND.1, IC1.2 (V-), L.C, PWR.C, R7.2, R8.2, R12.2, R13.2, RESET.P$3 (3), RESET.P$6 (6), ST1S1.EPAD, ST1S1.P$4 (AGND), ST1S1.P$5 (SYNC), ST1S1.P$8 (PGND), ST1S1.P$9 (GND), ST1S1.P$10 (GND), ST1S1.P$11 (GND), ST1S1.P$12 (GND), ST1S1.P$13 (GND), ST1S1.P$14 (GND), ST1S1.P$15 (GND), ST1S1.P$16 (GND), ST1S1.P$17 (GND), SW1.1, SW1.2, SW1.3, TB1.3 (PGND1), TB1.4 (PGND1'), TB1.9 (PGND2), TB1.10 (PGND2'), TB1.18 (GND), U1.3 (GND), U1.EXP (PAD)
IRC1: ATMEGA1.23 (PC4), SW1.6
IRC2: ATMEGA1.24 (PC5), SW1.5
IRC3: ATMEGA1.25 (PC6), SW1.4
M1: ATMEGA1.40 (PB0), TB1.22 (AIN2)
M2: ATMEGA1.41 (PB1), TB1.21 (AIN1)
M3: ATMEGA1.42 (PB2), TB1.17 (BIN1)
M4: ATMEGA1.26 (PC7), TB1.16 (BIN2)
MISO: ATMEGA1.2 (PB6/MISO), AVR_SPI_PRG.1, U$6.5
MISO*: AVR_SPI_PRG1.1, U1.17 ((PD0/MISO/PCINT3)PB3)
MOSI: ATMEGA1.1 (PB5/MOSI), AVR_SPI_PRG.4, U$6.4
MOSI*: AVR_SPI_PRG1.4, U1.16 ((PDI/MOSI/PCINT2)PB2)
unnamed: PWR.A, R17.1
unnamed: $$$$U$1.P$1 (1), C23.+, CN2.PWR, D2.A
unnamed: R3.2, RX1.A
unnamed: R4.2, TX1.A
unnamed: C15.2, CRYSTAL2.1, U1.2 (XTAL2(PC0))
unnamed: ATMEGA1.27 (AVCC), R2.2
unnamed: C17.2, CRYSTAL2.3 (2), U1.1 (XTAL1)
unnamed: C19.2, U1.27 (UCAP)
unnamed: C20.1, R12.1, U1.13 ((CTS/HWB/AIN6/TO/INT7)PD7)
unnamed: L2.2, X1.M1, X1.M2, X1.M3, X1.M4, Z1.2, Z2.2
unnamed: CN1.3, D3.C
unnamed: L.A, R1.1
unnamed: F1.1, X1.1
unnamed: R15.2, X1.2, Z1.1
unnamed: R16.2, X1.3, Z2.1
unnamed: L1.P$1 (1), ST1S1.P$7 (SW)
unnamed: C16.2, R8.1, R10.2, ST1S1.P$3 (VFB)
unnamed: ATMEGA1.8 (XTAL2), C11.1, CRYSTAL1.3 (2)
unnamed: ATMEGA1.7 (XTAL1), C12.1, CRYSTAL1.1
PC2: ATMEGA1.21 (PC2), R1.2
PD6: ATMEGA1.15 (PD6), U$6.7
PD7: ATMEGA1.16 (PD7), U$6.8
PWM1: ATMEGA1.13 (PD4), TB1.23 (PWMA)
PWM2: ATMEGA1.14 (PD5), TB1.15 (PWMB)
RESET: ATMEGA1.4 (!RESET), AVR_SPI_PRG.5, C20.2, R18.1, RESET.P$2 (2), RESET.P$5 (5)
RESET2: AVR_SPI_PRG1.5, D1.A, R14.1, U1.24 (RESET(PC1/DW))
RX0: ATMEGA1.9 (PD0/RX0), D3.A, R5.1
RXLED1: RX1.C, U1.10 ((INT5/AIN3)PD4)
RXO': R5.2, U1.9 ((TXD1/INT3)PD3)
SCK: ATMEGA1.3 (PB7/SCK), AVR_SPI_PRG.3, U$6.6
SCK*: AVR_SPI_PRG1.3, U1.15 ((SCLK/PCINT1)PB1)
SCL: ATMEGA1.19 (PC0/SCL), U$6.1
SDA: ATMEGA1.20 (PC1/SDA), U$6.2
STBY: ATMEGA1.22 (PC3), TB1.19 (STBY)
TX0: ATMEGA1.10 (PD1/TX0), CN1.2, R6.1
TX0': R6.2, U1.8 ((RXD1/AIN1/INT2)PD2)
TXLED1: TX1.C, U1.11 ((XCK/AIN4/PCINT12)PD5)
UGND: C19.1, GROUND.2, L2.1, U1.28 (UGND), X1.5
VIN: C5.1, C6.1, C18.1, C21.1, D2.C, R9.1, ST1S1.P$1 (VIN_A), ST1S1.P$2 (EN), ST1S1.P$6 (VIN_SW), TB1.13 (VM2), TB1.14 (VM3), TB1.24 (VM1), VIN.P$1

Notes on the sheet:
ATMEGA1284
MOTOR CONTROLLOR
USB TO SERIAL
POWER SUPPLY
FIDUCIAL
TEST PADS
EBot8



Board: 2 copper layers, 62.0 x 70.5 mm, 89 parts (3 on the bottom side), 73 nets.

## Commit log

2018-04-12 Initial Commit to GitHub
    Initial Commit to GitHub
    [Ebot8_v_1.2.brd, Ebot8_v_1.2.sch, Ebot8_v_2.brd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]
2018-04-12 EBot-8 design
    [Ebot8_v_1.2.brd, Ebot8_v_1.2.sch, Ebot8_v_2.brd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]
2018-04-12 EBot sensors
    [SensorNodePCB_set1_v2_wo_Relay.brd, SensorNodePCB_set1_v2_wo_Relay.sch, SensorNodePCB_set2_v2.brd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]
2018-04-12 EBot Sunny
    [EbotSunny-v02.brd, EbotSunny-v02.sch]

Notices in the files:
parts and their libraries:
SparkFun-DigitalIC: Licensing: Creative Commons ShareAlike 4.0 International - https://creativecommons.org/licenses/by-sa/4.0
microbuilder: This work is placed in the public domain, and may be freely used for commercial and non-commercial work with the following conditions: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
